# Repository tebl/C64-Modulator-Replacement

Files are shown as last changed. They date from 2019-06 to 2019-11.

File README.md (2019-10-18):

# C64 Modulator replacement ("Longboard" edition)

Based on the C64 RF-modulator mod by [Zero-X / OMS](https://github.com/tebl/C64-Modulator-Replacement/raw/master/gallery/modulator_simple.png), this adapts those schematics to create a complete replacement for the original modulator including a few changes of my own. A nice writeup and the my original inspiration for making this version if it came from a blog post on [My Diy Blog](https://amazingdiy.wordpress.com/2013/02/08/c64-s-video-mod/) (not actually my blog, it's just called that).

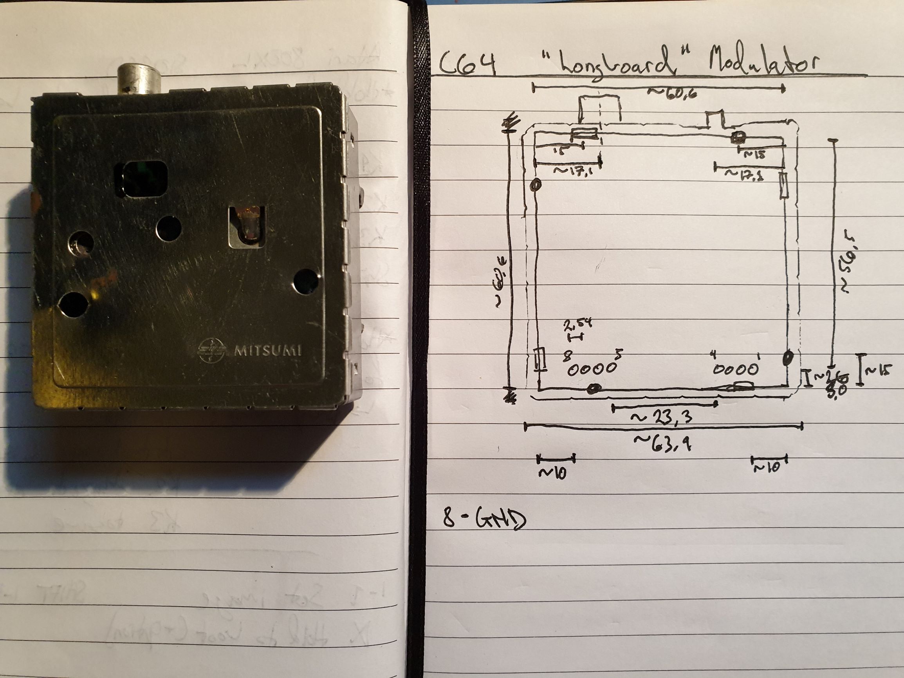
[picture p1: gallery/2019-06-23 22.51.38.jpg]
Modulator


The modulator replacement replaces the original circuit, with the original responsible for boosting the output from the VIC-chip and generating composite video, S-Video and the RF-signal. The replacement removes the old RF-signal output as well as the noise it provides, also added to it is options for bypassing some of the more problematic signals and a connector for adding stereo audio output. S-Video picture quality can be further improved upon by not installing the components for composite video.

Given differences in pinouts and voltages found on various Commodore 64 revisions, this variant is only meant for installation on Commodore 64s with so-called "longboards" only!

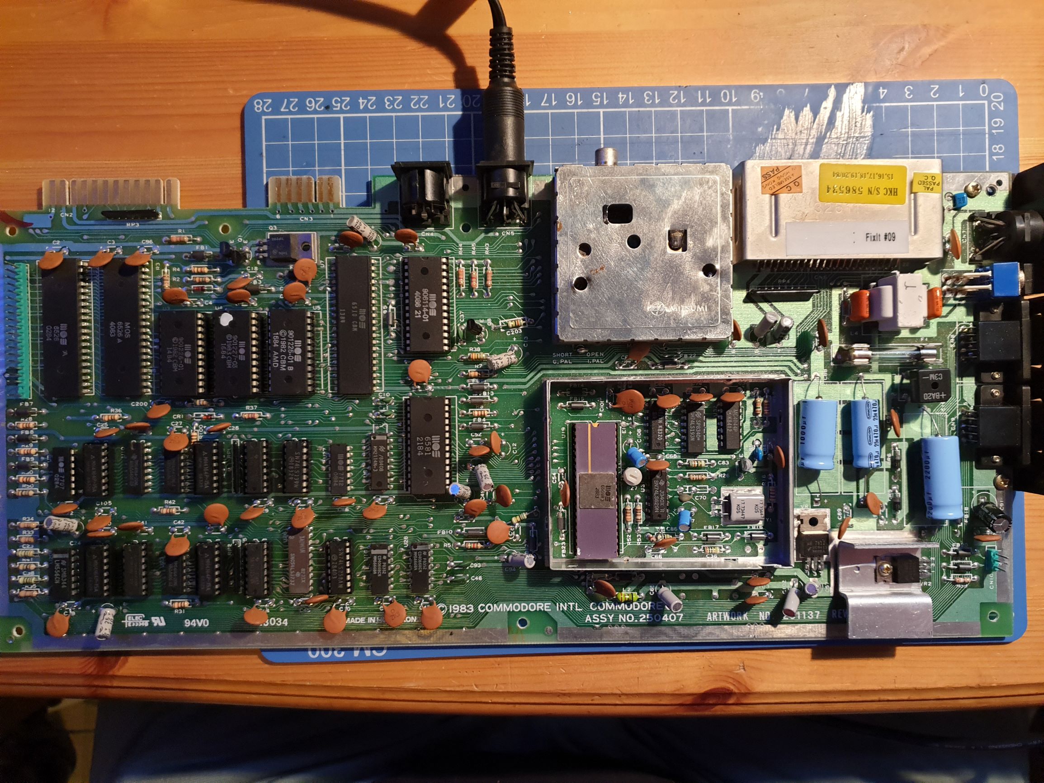
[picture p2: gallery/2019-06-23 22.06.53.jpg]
Longboard


## Building the board
Soldering together the few components should be easy going as long as you have access to reasonable tools, personally I'm using a cheap soldering station with adjustable temperature so no need to go expensive if you don't have to. Use 60/40 soldering tin, the lead free kind makes the job a lot harder if you're new to the hobby.

Start by studying the PCB, both sides and perform dry fits where needed so that you have an idea of where everything should go since removing components is always a lot harder than getting it right in the first place. In particular, take care when it comes to the orientation of polarized components such as the electrolytic capacitors and diodes (match orientation to symbols, study the gallery images for reference). Perhaps the most important part is that since this board will be mounted on the C64-mainboard, there is large sections of exposed ground planes directly beneath where the modulator goes - you'll need to make sure nothing'll short between this part and the modulator replacement above, so cut leads short.

I recommend the following sequence when soldering the board together:
1. Check errata below for relevant changes
2. Decide if you want composite video, if not - identify components that do not need installing (see underside of board)
2. Resistors, diodes, inductors and non-polarized capacitors.
3. 7805 regulator
4. Transistors
5. Connectors (if needed)
6. See installing the board for the continuation, board alignment etc...

### Errata
- Revision B has bypass capacitors marked C8/C9, these are not necessary as they are already on the motherboard and the Stereo SID board. Having them there changes the sound experience somewhat, either leave them in place or replace them with a piece of wire.

## Installing the board
The first part of installing the board in a Commodore 64 with a longboard is removing the old regulator, this is a crucial step and is only recommended for people with experience working on antique hardware boards and have suitable equipment for doing so (excess heat over time = broken PCB). Free up the tabs holding the regulator, these are usually bent at an angle to grip and then soldered in place so you'll have to remove the solder and bend them back. Desolder the signal wires, two sections of four pins going into the modulator from the underside. Carefully probe each piece to ensure that it is loose before attempting to remove the modulator completely - impatience means broken traces!

With the old modulator removed, inspect the input pins to make sure that they're all still there and coninuity is sufficiently there before doing anything else. At this point in development you wouldn't want to subject the PCB to any more heat as it's already taken a lot, so what I recommend is installing male pin headers on the various connecting sections on the motherboard. Use the modulator replacement as a way of lining it all up, but only solder the male pins on the underside of the motherboard! Finally, remove modulator replacement and put some female headers on top of the pin headers just installed - put modulator replacement on top of those and solder in place just to get the alignment correct.

You should now have a modulator that can easily be removed from the machine if needed, that way you can easily upgrade to a later version of the module without taking the soldering iron to the C64 motherboard and quite possibly adjust the values to suit the picture if need be.

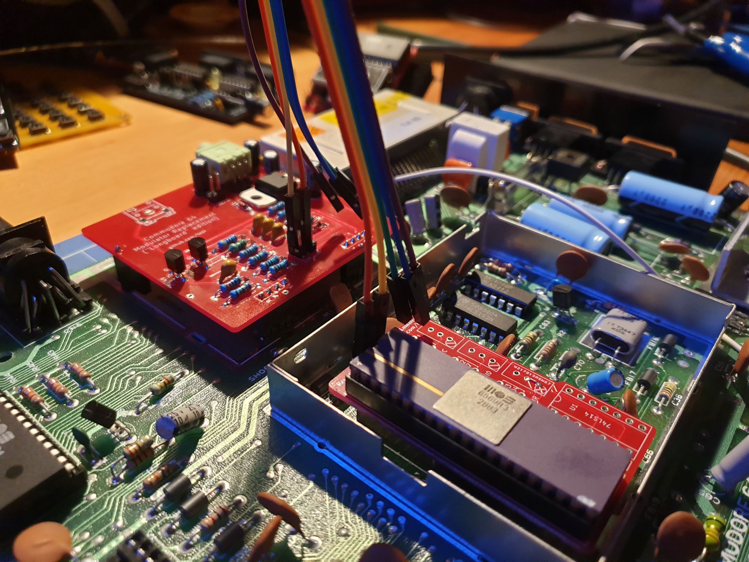
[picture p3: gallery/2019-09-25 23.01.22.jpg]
Modulator and Lumafix


When connecting the board to the computer without any other hardware, you'd need to jumper across the two headers named LUM and CHR to connect the input signals to the motherboard. On most machines I've tried it with you'll get heavy jailbars on the screen, this is what the signal looks like coming into the modulator without the fuzzyness/smoothing added by the old one. This is where a board such as a Lumafix comes into the picture, it attempts to counteract the noise by adding some of it's own and smooth the signal somewhat (in essence, noise-cancelling instead of using a cleaner source). I've added a secondary connector at the top of my own [Lumafix-board](https://github.com/tebl/C64-Lumafix), this allows you to run the LUM and CHR signals directly from the VIC instead of running them across the motherboard.

Pictures below are taken from my system using composite cables from [RetroComputerShack](https://retrocomputershack.com/), some moire patterns appear due to me taking a picture of the LCD-screen using a mobile phone.

Basic blue screen
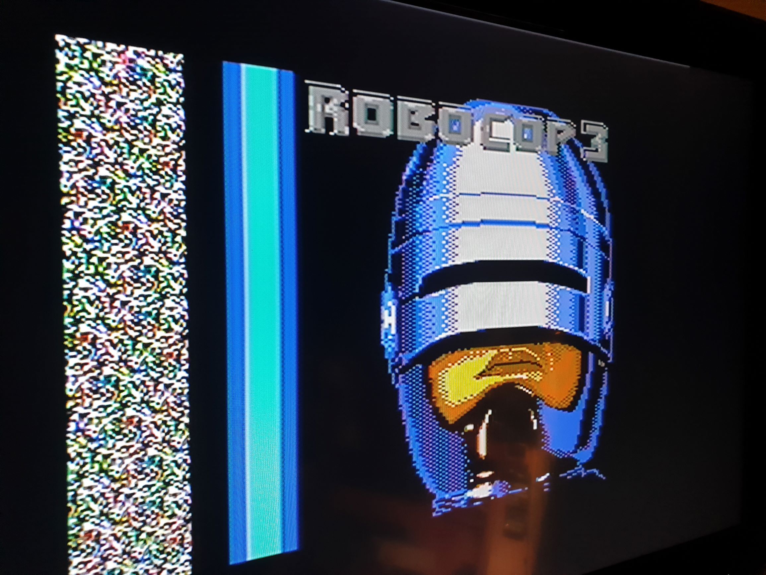
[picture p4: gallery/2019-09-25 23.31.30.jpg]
Robocop 2 title screen


# Schematic
The supplied KiCad files should be sufficient as both a schematic and as a  starting point for ordering PCBs (basically you could just zip the contents of the export folder and upload that on a fabrication site), the schematic is also available in [PDF-format](https://github.com/tebl/C64-Modulator-Replacement/raw/master/export/C64%20Modulator.pdf) and this is what you'll need to print and work your way through this things don't work as expected after assembly. The original schematic by 

# BOM
Most parts should be easy to get a hold of from your favourite local electronic component shop, but given that I don't have access to such shops where I live so everything was based on whatever I could get cheapest from ebay/AliExpress (free shipping, plan on usually waiting 3-4 weeks though). The list below should be everything you'll need in addition to a workable soldering iron and some 60/40 soldering tin.

Pin headers you order in bulk and snap off parts as needed, relevant part details should also be present on the PCB itself for easy reference while assembling. Some components have been put in parenthesis, C2/C3 provide extra filtering while the rest is for adding composite output.

| Reference | Item | Count |
| --- | --- | ----- |
| PCB | Fabricate using Gerber files | 1 |
| C1 | 330pF capacitor | 1 |
| C3 | 330pF capacitor | (1)|
| D1,D2 | 1N4148 small signal diode | 2 |
| C2 | 150pF capacitor | (1)|
| C4 | 10uF electrolytic capacitor (16v) | 1 |
| C5 | 100uF electrolytic capacitor (16v) | 1 |
| C6 | 68pF capacitor | (1)|
| C7 | 100nF capacitor | 1 |
| L1 | 22uH axial inductor | 1 |
| L2 | 10uF axial inductor | (1)|
| Q1-Q2 | BC549 transistor (TO-92) | 2 |
| R1 | 1k ohm resistor | 1 | 
| R2 | 3k3 ohm resistor | 1 | 
| R3 | 5k6 ohm resistor | 1 | 
| R4 | 68 ohm resistor | 1 | 
| R5 | 220 ohm resistor | 1 | 
| R6 | 470 ohm resistor | 1 | 
| R7,R12 | 150 ohm resistor | 2 | 
| R8,R11 | 150 ohm resistor | (2)| 
| U1 | LM7805 (TO-220) | 1 |
| | Male header pins (break to size) | 1 |
| | 2pin female header* | 2 |
| J2,J3 | 4pin female header | 2 |
| J5 Audio | 3.5mm 5pin green audio socket (PJ307) | (1)|

\* Usually 1pin male pin header is soldered to ground points on the outer edges, usually a 1pin female header would be impractical so I use a 2pin or more female header with the rest of the pins pulled out.

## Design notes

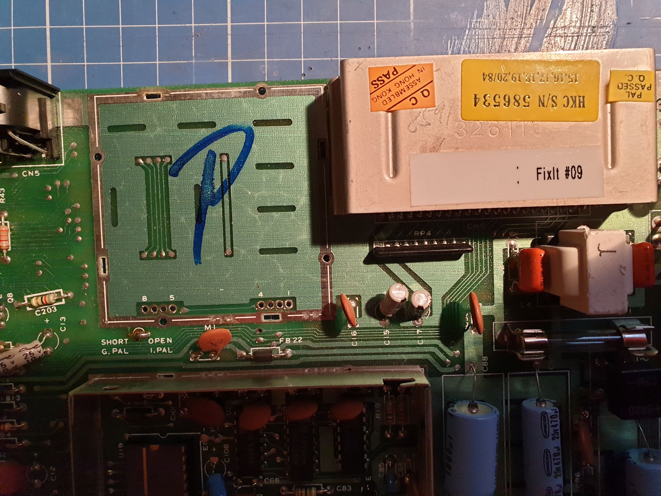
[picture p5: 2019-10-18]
gallery/2019-06-23 22.23.52.jpg

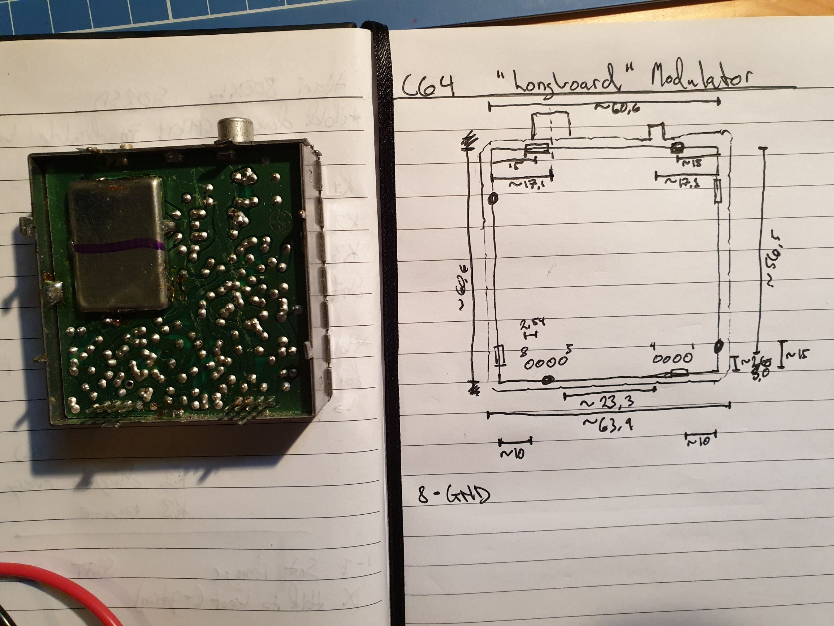
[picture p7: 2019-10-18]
gallery/2019-06-23 22.51.17.jpg

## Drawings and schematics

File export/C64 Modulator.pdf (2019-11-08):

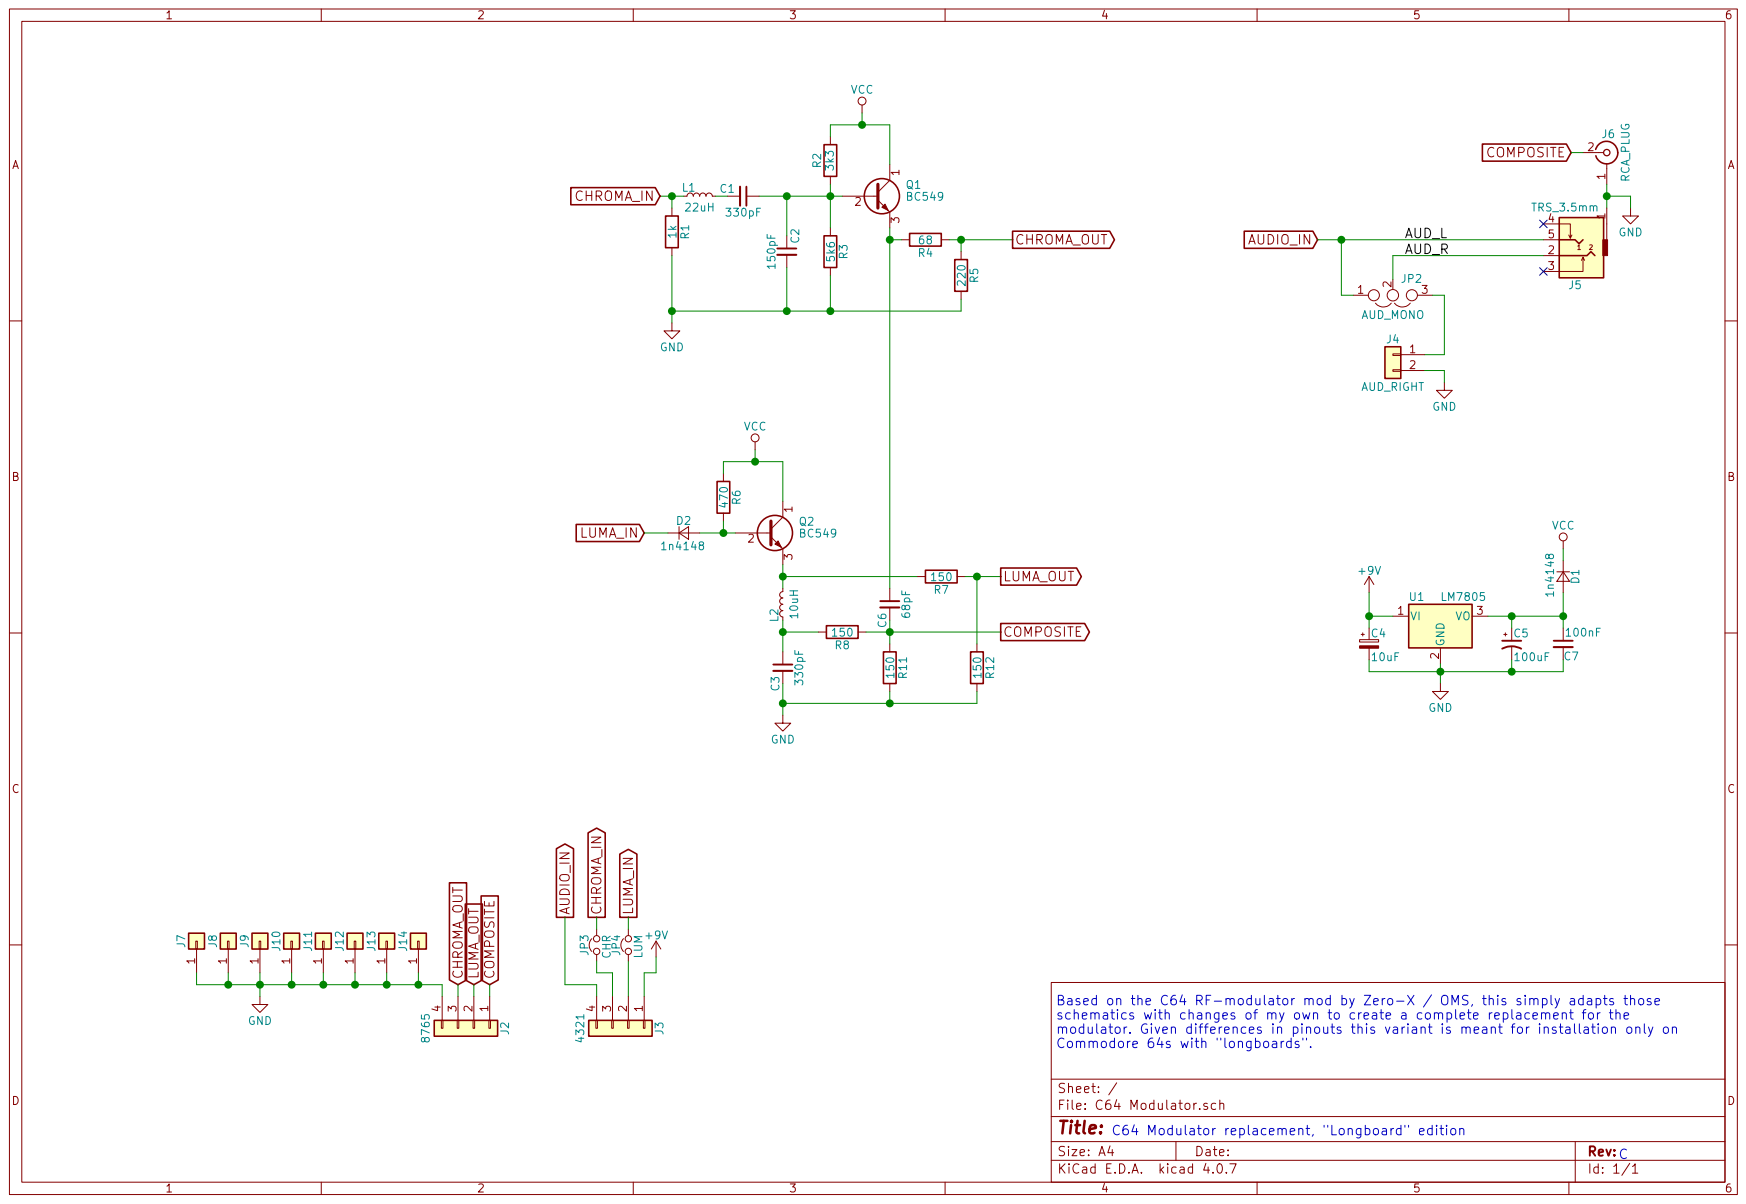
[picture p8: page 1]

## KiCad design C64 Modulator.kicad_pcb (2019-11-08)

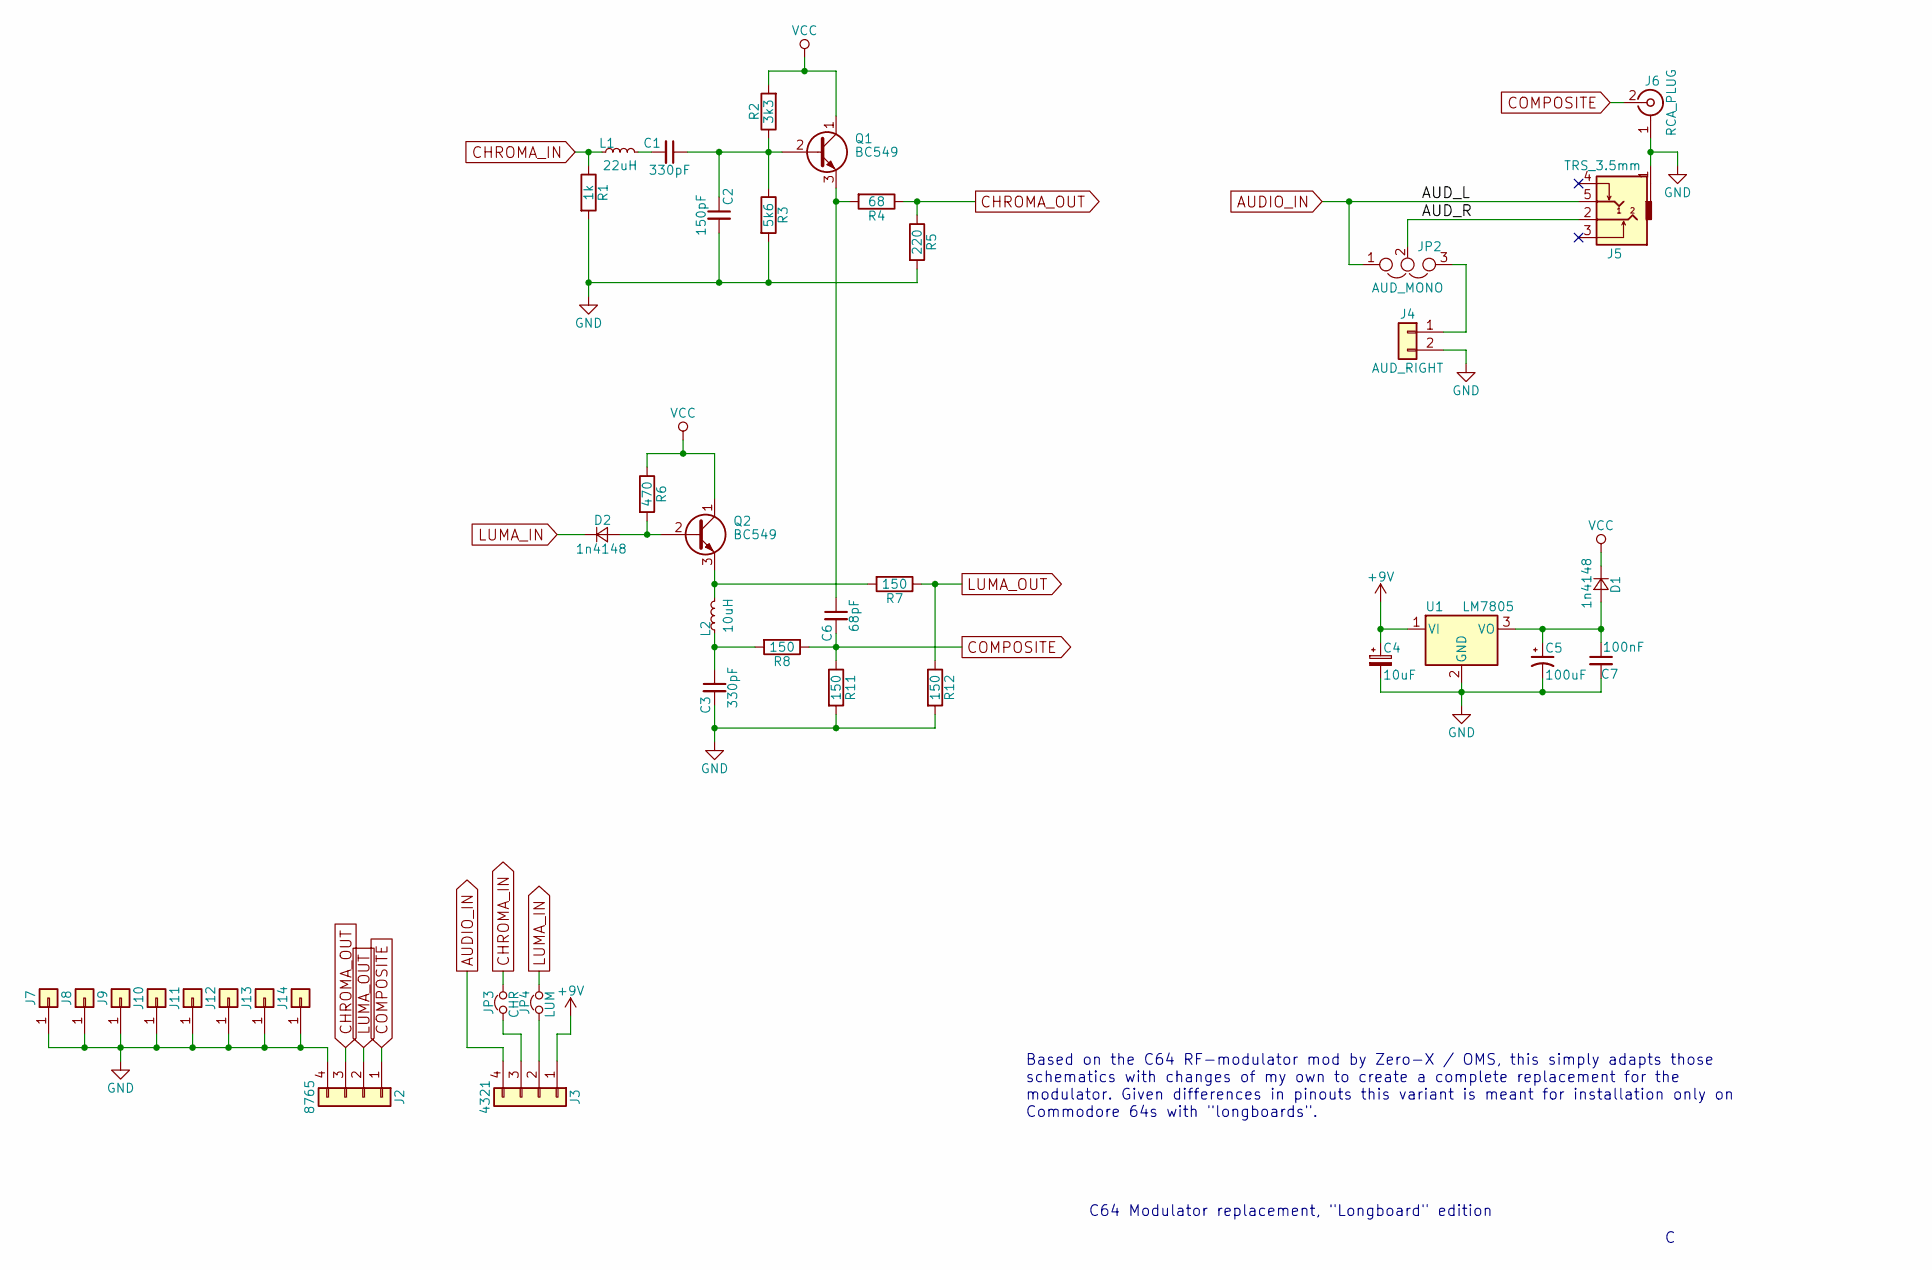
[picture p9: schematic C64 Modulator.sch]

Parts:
C1, C3: 330pF; C_Disc_D4.7mm_W2.5mm_P5.00mm
C2: 150pF; C_Disc_D4.7mm_W2.5mm_P5.00mm
C4: 10uF; CP_Radial_D5.0mm_P2.50mm
C5: 100uF; CP_Radial_D5.0mm_P2.50mm
C6: 68pF; C_Disc_D4.7mm_W2.5mm_P5.00mm
C7: 100nF; C_Disc_D4.7mm_W2.5mm_P5.00mm
D1, D2: 1n4148; D_DO-35_SOD27_P7.62mm_Horizontal
J2: 8765; Pin_Header_Straight_1x04_Pitch2.54mm
J3: 4321; Pin_Header_Straight_1x04_Pitch2.54mm
J4: AUD_RIGHT; Pin_Header_Straight_1x02_Pitch2.54mm
J5: TRS_3.5mm; Tayda_3.5mm_stereo_TRS_jack_A-853
J6: RCA_PLUG; rca_yellow
J7, J8, J9, J10, J11, J12, J13, J14: anchor_circle
JP2: AUD_MONO; Pin_Header_Straight_1x03_Pitch2.54mm
JP3: CHR; Pin_Header_Straight_1x02_Pitch2.54mm
JP4: LUM; Pin_Header_Straight_1x02_Pitch2.54mm
L1: 22uH; L_Axial_L6.6mm_D2.7mm_P10.16mm_Horizontal_Vishay_IM-2
L2: 10uH; L_Axial_L6.6mm_D2.7mm_P10.16mm_Horizontal_Vishay_IM-2
Q1, Q2: BC549; TO-92_Inline_Wide
R1: 1k; R_Axial_DIN0207_L6.3mm_D2.5mm_P10.16mm_Horizontal
R2: 3k3; R_Axial_DIN0207_L6.3mm_D2.5mm_P10.16mm_Horizontal
R3: 5k6; R_Axial_DIN0207_L6.3mm_D2.5mm_P10.16mm_Horizontal
R4: 68; R_Axial_DIN0207_L6.3mm_D2.5mm_P10.16mm_Horizontal
R5: 220; R_Axial_DIN0207_L6.3mm_D2.5mm_P10.16mm_Horizontal
R6: 470; R_Axial_DIN0207_L6.3mm_D2.5mm_P10.16mm_Horizontal
R7, R8, R11, R12: 150; R_Axial_DIN0207_L6.3mm_D2.5mm_P10.16mm_Horizontal
U1: LM7805; TO-220-3_Horizontal

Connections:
+9V: C4.1, J3.1, U1.1 (VI)
/AUD_R: J5.2, JP2.2
AUDIO_IN: J3.4, J5.5, JP2.1
CHROMA_IN: JP3.1, L1.1, R1.1
CHROMA_OUT: J2.3, R4.1, R5.1
COMPOSITE: C6.2, J2.1, J6.2 (In), R8.1, R11.1
GND: C2.2, C3.2, C4.2, C5.2, C7.2, J2.4, J4.2, J5.1, J6.1 (Ext), J7.1, J8.1, J9.1, J10.1, J11.1, J12.1, J13.1, J14.1, R1.2, R3.2, R5.2, R11.2, R12.2, U1.2 (GND)
LUMA_IN: D2.1 (K), JP4.1
LUMA_OUT: J2.2, R7.1, R12.1
unnamed: C1.1, C2.1, Q1.2 (B), R2.1, R3.1
unnamed: C1.2, L1.2
unnamed: C3.1, L2.1, R8.2
unnamed: C5.1, C7.1, D1.2 (A), U1.3 (VO)
unnamed: C6.1, Q1.3 (E), R4.2
unnamed: D2.2 (A), Q2.2 (B), R6.2
unnamed: J3.2, JP4.2
unnamed: J3.3, JP3.2
unnamed: J4.1, JP2.3
unnamed: L2.2, Q2.3 (E), R7.2
VCC: D1.1 (K), Q1.1 (C), Q2.1 (C), R2.2, R6.1

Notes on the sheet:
Based on the C64 RF-modulator mod by Zero-X / OMS, this simply adapts those schematics with changes of my own to create a complete replacement for the modulator. Given differences in pinouts this variant is meant for installation only on Commodore 64s with "longboards".
C64 Modulator replacement, "Longboard" edition

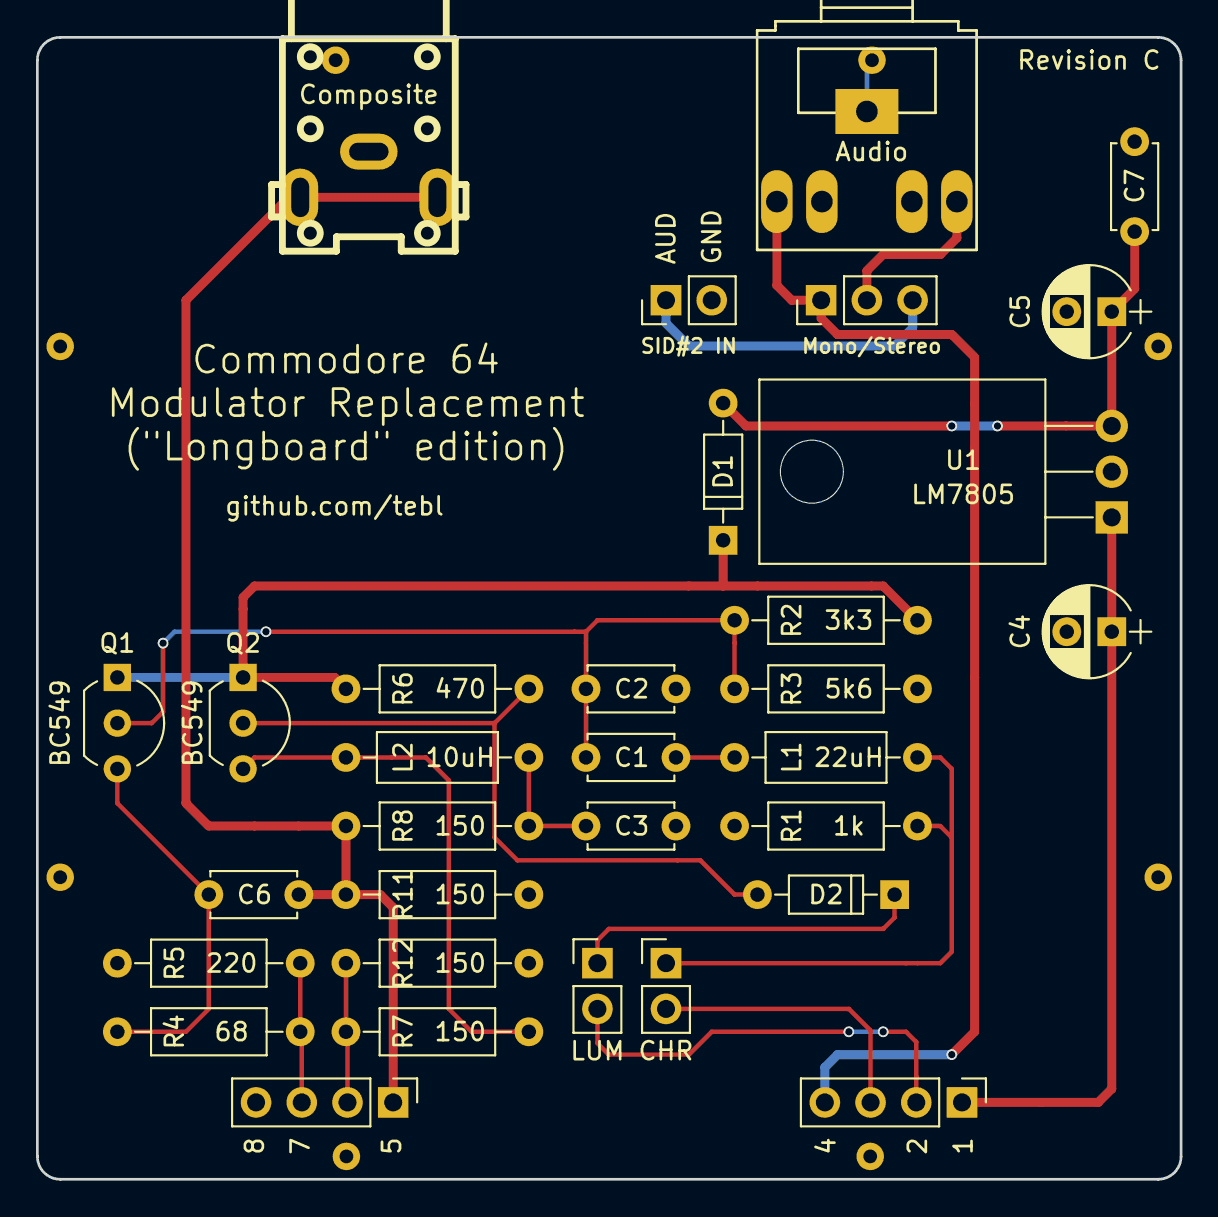
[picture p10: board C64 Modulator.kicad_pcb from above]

Board: 2 copper layers, 63.5 x 63.4 mm, 40 parts (0 on the bottom side), 20 nets.

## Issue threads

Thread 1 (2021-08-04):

Composite port part...

Shadowtrance, 2021-08-04:
Do you have a part reference for the rca jack for the composite out at all? or a link to one on aliexpress etc that will fit.
I was going to salvage one from some old boards i have buuuuuut they're a different footprint -_-
Yes, I'm building all your things. :)

TheSupremeMonkey, 2021-09-01:
> Do you have a part reference for the rca jack for the composite out at all? or a link to one on aliexpress etc that will fit.
> I was going to salvage one from some old boards i have buuuuuut they're a different footprint -_-
> Yes, I'm building all your things. :)

I was looking for the same information. I can't seem to find the right part to match the footprint on the PCB.

tebl, 2021-09-01:
The ones I've been using have been linked below, pretty sure I've bought a
few of AliExpress as well.

https://www.ebay.com/itm/20-pcs-3P-PCB-Mounting-gelb-1-RCA-Buchse-Steckdose-Jack-Audio-Video-AV-Anschlus-/154387168195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

NOK 11.36  5%OFF | 10PCS/LOT AV-8.4-5 2x Holes 3Pins RCA Sockets 90Degree
Audio Video Connecctors Jacks yellow white red
https://a.aliexpress.com/_mLwKCcF

ons. 1. sep. 2021, 15:55 skrev TheSupremeMonkey ***@***.***>:

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

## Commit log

2019-06-21 Added schematic
    [C64 Modulator.kicad_pcb, C64 Modulator.sch]
2019-06-21 Assigned footprints
    [C64 Modulator.sch]
2019-06-26 Layout and silkscreen done
    [C64 Modulator.kicad_pcb, C64 Modulator.sch]
2019-06-26 Gerber export
    [C64 Modulator-B.Cu.gbl, C64 Modulator-B.Mask.gbs, C64 Modulator-B.Paste.gbp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]
2019-06-26 Added component notices to PCB
    [C64 Modulator-B.Cu.gbl, C64 Modulator-B.Mask.gbs, C64 Modulator-B.Paste.gbp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]
2019-08-08 Added 5v regulator to board
    [C64 Modulator-B.Cu.gbl, C64 Modulator-B.Mask.gbs, C64 Modulator-B.Paste.gbp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]
2019-08-08 Readded D1
    [C64 Modulator-B.Cu.gbl, C64 Modulator-B.Mask.gbs, C64 Modulator-B.Paste.gbp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]
2019-08-15 Audio decoupling caps on schematic
    [C64 Modulator.sch]
2019-08-17 Assigned updated footprints
    [C64 Modulator.sch]
2019-08-17 Updated PCB layout
    [C64 Modulator-B.Cu.gbl, C64 Modulator-B.Mask.gbs, C64 Modulator-B.Paste.gbp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]
2019-10-18 Removed C8/C9
    [C64 Modulator-B.Cu.gbl, C64 Modulator-B.Mask.gbs, C64 Modulator-B.Paste.gbp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]
2019-11-08 Updated gerbers
    [C64 Modulator-B.Cu.gbl, C64 Modulator-B.Mask.gbs, C64 Modulator-B.Paste.gbp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]
